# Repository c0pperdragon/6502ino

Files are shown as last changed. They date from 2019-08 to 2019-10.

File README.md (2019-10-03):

# 6502ino

A minimal circuit to form the environment necessary to run a 65c02 CPU.

Normally getting any form of 6502 processor to run and communicate with the outside
world is very cumbersome. In addition to the CPU and RAM you need very specific 
IO controller parts that can be hooked up to the system address and data bus.
You need a ROM for the initial boot code and some form of MMU to drive the various
selection lines according to the memory address (all IO is memory mapped).
All this leads to a pretty large and costly board even for the most basic 
program to execute.

This project tries to reduce the system size as much as possible by
using a microcontroller - in the form of an Arduino Uno - to do all the
tricky stuff. Together with only a bit of 7400 series logic and 32KB RAM,
this is  enough to get the 65c02 working with 16Mhz on a breadboard.

### Setting the fuses to generate 16Mhz on pin 8

For the setup to work, you need to configure your arduino to permanently
ouput the full system clock on a dedicated pin. This feature can not be set up
from inside a program, but needs to be done by configuring the "fuse bits". 

Setting the fuse bits is a bit complicated, but you only need to do it once. 
To access these bits, you need a dedicated programming device, called the 
AVR ISP (in-circuit-programmer). Luckily any arduino can be programmed to become 
such a device with the "ArduinoISP" example sketch that is included in the 
Arduino IDE. So you basically need a spare arduino for this process.

Wiring up the programmer arduino to the arduino being programmed can be seen in
countless internet resources. But there it is mainly done to programm a bootloader.
You need to do a different thing, for which you need the command-line tool "avrdude.exe"
which is installed along with the Arduino IDE somewhere in the depth of the "hardware/tools"
folder. 

Once everything is hooked up, open a system console and execute the following command (replace com10 
with whatever port your programmer arduino is registered in the system):
```
avrdude -p atmega328p -b 19200 -C ../etc/avrdude.conf -c avrisp -P com10
```

If everything works correctly, this will show you some status and the current settings of the
fuse bits. We are particularly interested in the value of the 'L' fuse bits, which on my
factory default Arduino Uno shows as L:FF. To set the permanent clock output, you need
to modify this value (an 8-bit value) to have the bit 6 set to 0. In my case this means

to set the 'L' fuses to BF:
```
avrdude -p atmega328p -b 19200 -C ../etc/avrdude.conf -c avrisp -P com10 -U lfuse:w:0xBF:m
```

After this settings are done, the Arduino will constantly send a 16Mhz signal on pin 8, 
no matter what, even during reset.

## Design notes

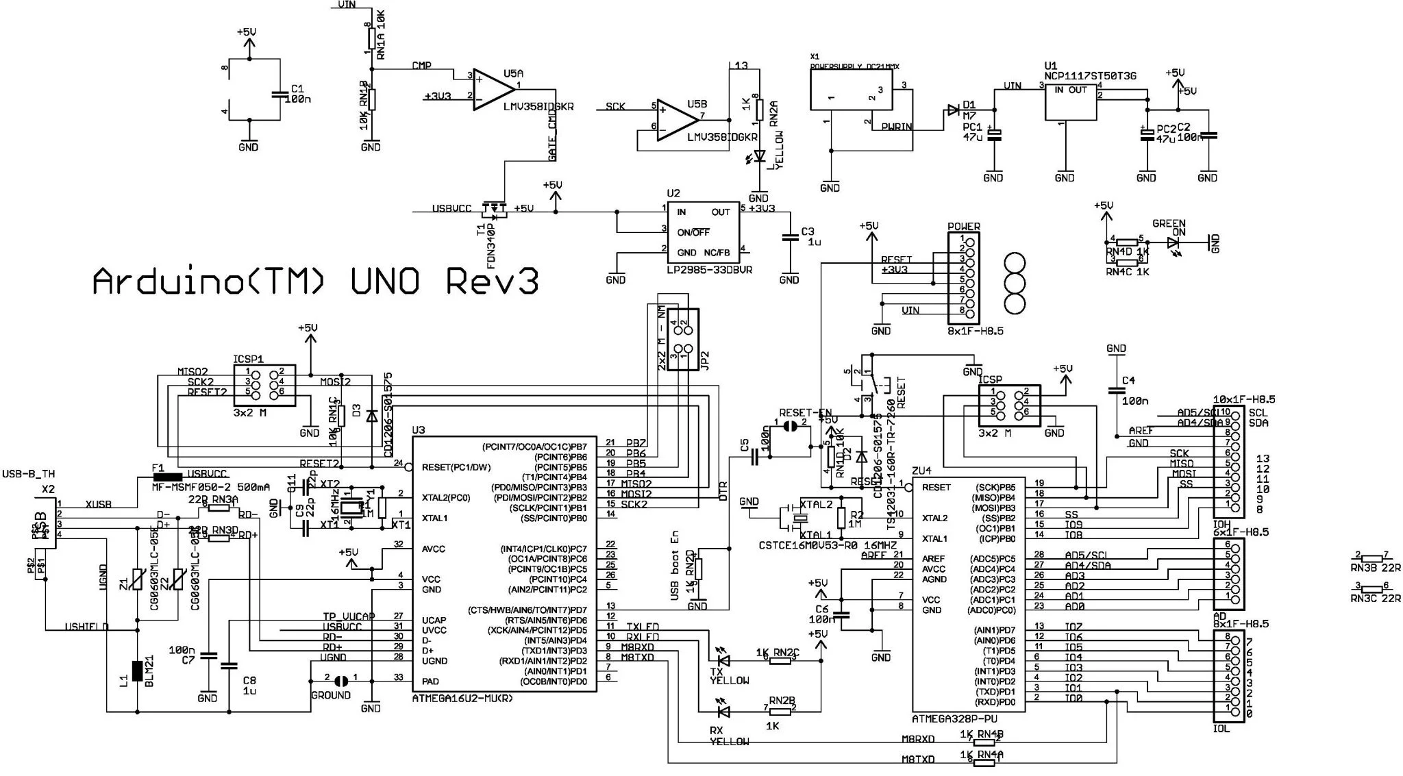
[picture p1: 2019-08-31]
doc/Arduino-Uno-R3-Schematic-Diagram.webp

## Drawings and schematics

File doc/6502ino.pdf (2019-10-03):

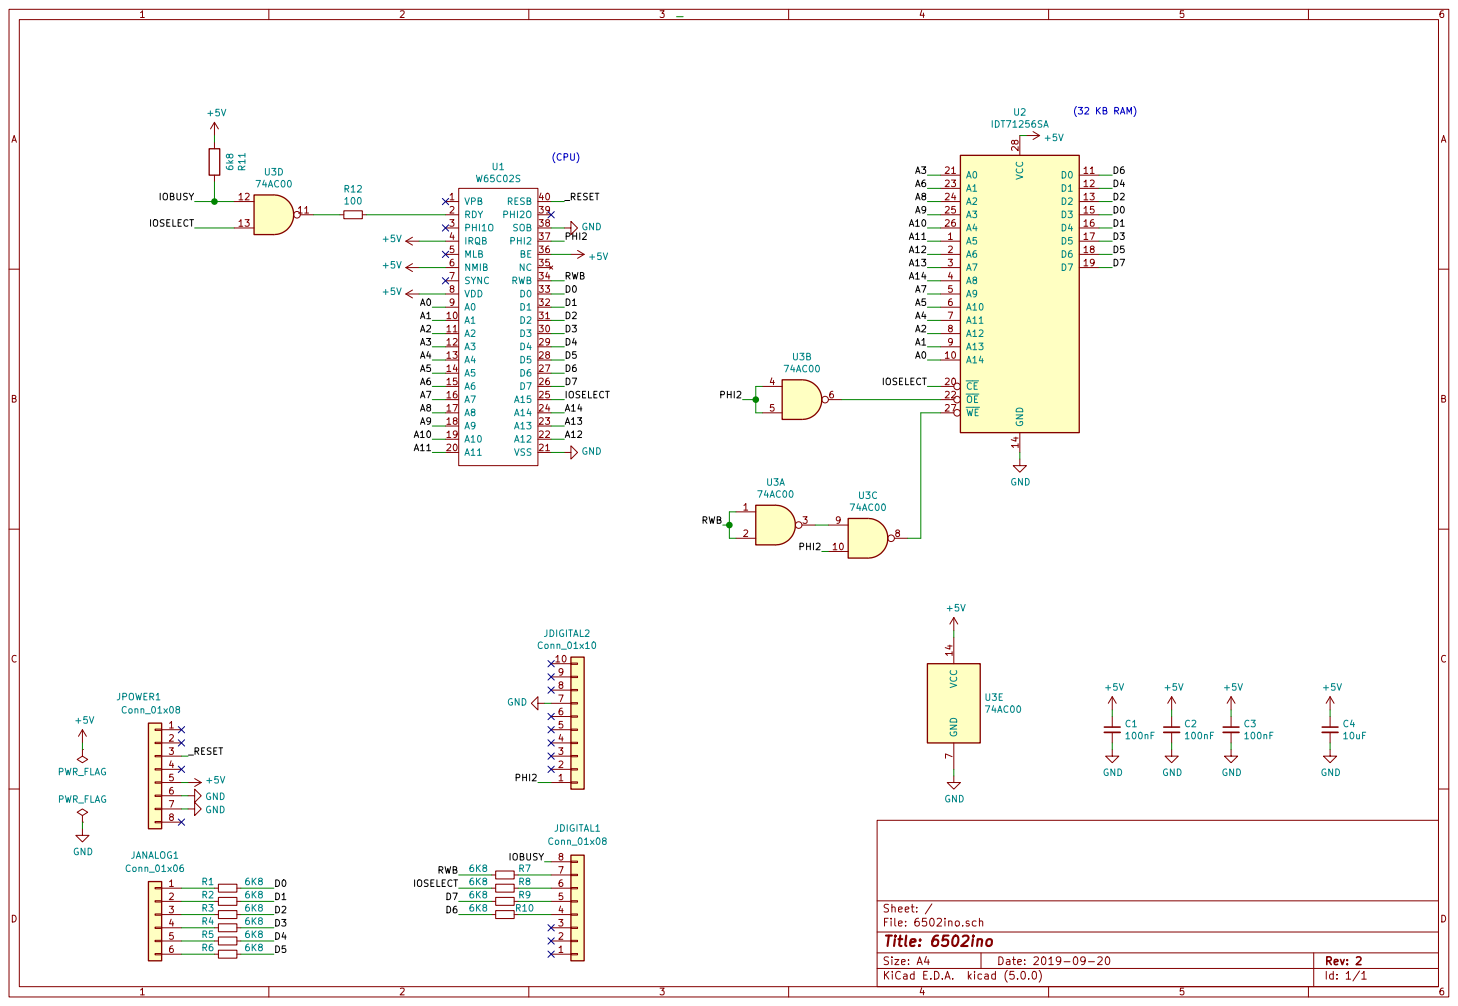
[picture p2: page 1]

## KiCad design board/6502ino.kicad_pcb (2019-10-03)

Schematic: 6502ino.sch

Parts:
C1, C2, C3: 100nF; C_Disc_D3.0mm_W1.6mm_P2.50mm
C4: 10uF; C_Disc_D4.3mm_W1.9mm_P5.00mm
JANALOG1: Conn_01x06; PinSocket_1x06_P2.54mm_Vertical
JDIGITAL1: Conn_01x08; PinSocket_1x08_P2.54mm_Vertical
JDIGITAL2: Conn_01x10; PinSocket_1x10_P2.54mm_Vertical
JPOWER1: Conn_01x08; PinSocket_1x08_P2.54mm_Vertical
R1, R2, R3, R4, R5, R6, R7, R8, R9, R10: 6K8; R_Axial_DIN0207_L6.3mm_D2.5mm_P7.62mm_Horizontal
R11: 6k8; R_Axial_DIN0207_L6.3mm_D2.5mm_P7.62mm_Horizontal
R12: 100; R_Axial_DIN0207_L6.3mm_D2.5mm_P7.62mm_Horizontal
U1: W65C02S; DIP-40_W15.24mm_Socket
U2: IDT71256SA; DIP-28_W7.62mm_Socket
U3: 74AC00; DIP-14_W7.62mm_Socket

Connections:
+5V: C1.1, C2.1, C3.1, C4.1, JPOWER1.5, R11.1, U1.4, U1.6, U1.8, U1.36, U2.28, U3.14 (VCC)
/A0: U1.9, U2.10
/A1: U1.10, U2.9
/A2: U1.11, U2.8
/A3: U1.12, U2.21
/A4: U1.13, U2.7
/A5: U1.14, U2.6
/A6: U1.15, U2.23
/A7: U1.16, U2.5
/A8: U1.17, U2.24
/A9: U1.18, U2.25
/A10: U1.19, U2.26
/A11: U1.20, U2.1
/A12: U1.22, U2.2
/A13: U1.23, U2.3
/A14: U1.24, U2.4
/D0: R1.1, U1.33, U2.15
/D1: R2.1, U1.32, U2.16
/D2: R3.1, U1.31, U2.13
/D3: R4.1, U1.30, U2.17
/D4: R5.1, U1.29, U2.12
/D5: R6.1, U1.28, U2.18
/D6: R10.1, U1.27, U2.11
/D7: R9.1, U1.26, U2.19
/IOBUSY: JDIGITAL1.8, R11.2, U3.12
/IOSELECT: R8.1, U1.25, U2.20, U3.13
/PHI2: JDIGITAL2.1, U1.37, U3.4, U3.5, U3.10
/RWB: R7.1, U1.34, U3.1, U3.2
/_RESET: JPOWER1.3, U1.40
GND: C1.2, C2.2, C3.2, C4.2, JDIGITAL2.7, JPOWER1.6, JPOWER1.7, U1.21, U1.38, U2.14, U3.7 (GND)
unnamed: JANALOG1.1, R1.2
unnamed: JANALOG1.2, R2.2
unnamed: JANALOG1.3, R3.2
unnamed: JANALOG1.4, R4.2
unnamed: JANALOG1.5, R5.2
unnamed: JANALOG1.6, R6.2
unnamed: JDIGITAL1.4, R10.2
unnamed: JDIGITAL1.5, R9.2
unnamed: JDIGITAL1.6, R8.2
unnamed: JDIGITAL1.7, R7.2
unnamed: R12.1, U1.2
unnamed: R12.2, U3.11
unnamed: U2.22, U3.6
unnamed: U2.27, U3.8
unnamed: U3.3, U3.9

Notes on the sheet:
(32 KB RAM)
(CPU)

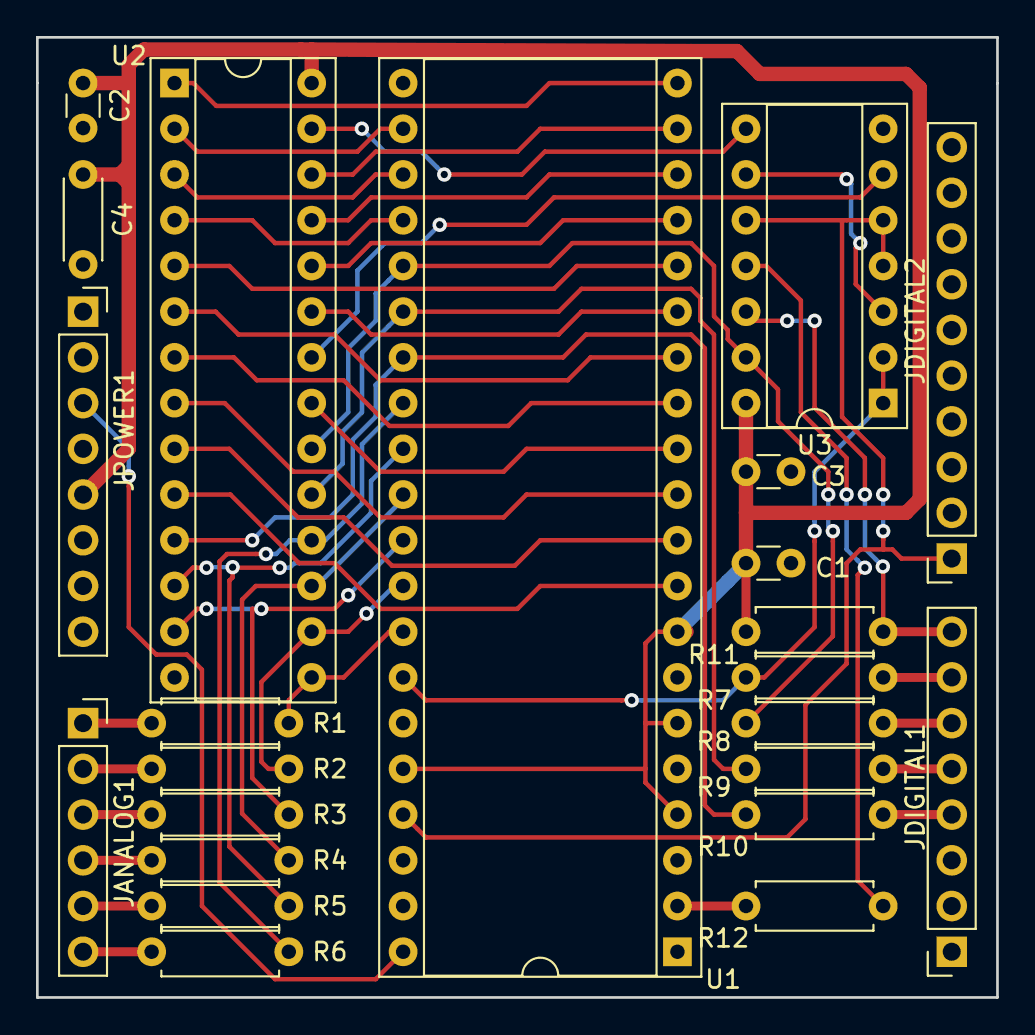
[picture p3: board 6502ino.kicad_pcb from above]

Board: 2 copper layers, 53.3 x 53.3 mm, 23 parts (0 on the bottom side), 45 nets.

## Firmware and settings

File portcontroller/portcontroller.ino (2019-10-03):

void setup()
{
  Serial.begin(9600);

  // configure signal input pins
  pinMode(5, INPUT); // IO request (active=0)
  pinMode(6, INPUT); // RWB (read=1)

  // configure bidirectional data pins to default non-pullup tri-state
  pinMode(A0, INPUT);  // D0
  pinMode(A1, INPUT);  // D1
  pinMode(A2, INPUT);  // D2
  pinMode(A3, INPUT);  // D3
  pinMode(A4, INPUT);  // D4
  pinMode(A5, INPUT);  // D5
  pinMode(3, INPUT);   // D6
  pinMode(4, INPUT);   // D7

  // configure signal output pints
  digitalWrite(7, HIGH);
  pinMode(7, OUTPUT);  // IO ACK
}

void loop()
{
  byte data;

  int tries;
  for (tries = 0; tries < 100000; tries++)
  {
    // wait until the 65c02 requests IO
    while ((PIND & 0x20) == 0)  { };

    // read access
    if (PIND & 0x40)
    {
      // perform io operation
      data = readIO();

      // distribute the byte to port C and port D (keep ack inactive yet)
      PORTC = data & 0x3F;
      PORTD = ((data >> 3) & 0x18) | 0x80;
      DDRC = 0x3F;
      DDRD = 0x98;

      // add small delay to let outgoing signals get through the resistors
      DDRD = 0x98;
      DDRD = 0x98;
      DDRD = 0x98;
      DDRD = 0x98;
      DDRD = 0x98;
      DDRD = 0x98;
      DDRD = 0x98;
      DDRD = 0x98;
      DDRD = 0x98;

      noInterrupts();

      // pulse the ACK for exactly one clock
      PORTD = ((data >> 3) & 0x18);
      PORTD = 0x98;

      // bring bidirectional ports back to idle state
      DDRC = 0x00;
      DDRD = 0x80;
      PORTC = 0x00;

      interrupts();
    }
    // write access
    else
    {
      // small delay to let inputs stablize
      PORTD = 0x80;
      PORTD = 0x80;
      PORTD = 0x80;
      PORTD = 0x80;

      // collect data from port C and D
      data = (PINC & 0x3F) | ((PIND & 0x18) << 3);

      // perform io operation
      writeIO(data);

      // pulse the ACK for exactly one clock
      noInterrupts();

      PORTD = 0x00;
      PORTD = 0x80;

      interrupts();
    }
  }

  // stop program
  for (;;);
}


byte romcounter = 0;
const PROGMEM byte rom[] =
{
  // First data the 65c02 reads from IO space are NOP instructions.
  // When interpreted as the reset vector, the program counter will
  // be set to EAEA, and quite some additional NOPs are executed
  0xEA, 0xEA, 0xEA, 0xEA, 0xEA, 0xEA, 0xEA, 0xEA,
  0xEA, 0xEA, 0xEA, 0xEA, 0xEA, 0xEA, 0xEA, 0xEA,
  // because I do not know which byte the 65c02 takes for the
  // opcode, and which byte is just an idle fetch, I insert
  // a specific command that is crafted to bring the 65c02
  // onto the right track.
  // this is either LDA zp,x  (3 data fetches)
  // or a           LDA zp    (2 data fetches)
  0xB5, 0XA5, 0x00,
  // build this copy loop at address $0000:
  //      0000 AD FF FF   LDA $FFFF
  //      0003 8D 00 20   STA $0200
  //      0006 E6 04      INC $04
  //      0008 D0 F6      BNE -10
  //      000A E6 05      INC $05
  //      000C 10 F2      BPL -14
  //      000E 4C 00 70   JMP $7000
  0xA9, 0xAD, 0x85, 0x00,   // LDA imm, STA zp
  0xA9, 0xFF, 0x85, 0x01,   // LDA imm, STA zp
  0xA9, 0xFF, 0x85, 0x02,   // LDA imm, STA zp
  0xA9, 0x8D, 0x85, 0x03,   // LDA imm, STA zp
  0xA9, 0x00, 0x85, 0x04,   // LDA imm, STA zp
  0xA9, 0x02, 0x85, 0x05,   // LDA imm, STA zp
  0xA9, 0xE6, 0x85, 0x06,   // LDA imm, STA zp
  0xA9, 0x04, 0x85, 0x07,   // LDA imm, STA zp
  0xA9, 0xD0, 0x85, 0x08,   // LDA imm, STA zp
  0xA9, 0xF6, 0x85, 0x09,   // LDA imm, STA zp
  0xA9, 0xE6, 0x85, 0x0A,   // LDA imm, STA zp
  0xA9, 0x05, 0x85, 0x0B,   // LDA imm, STA zp
  0xA9, 0x10, 0x85, 0x0C,   // LDA imm, STA zp
  0xA9, 0xF2, 0x85, 0x0D,   // LDA imm, STA zp
  0xA9, 0x4C, 0x85, 0x0E,   // LDA imm, STA zp
  0xA9, 0x00, 0x85, 0x0F,   // LDA imm, STA zp
  0xA9, 0x02, 0x85, 0x10,   // LDA imm, STA zp
  // start the copy loop
  0x4C, 0x00, 0x00,         // JMP $0000

  // this is the actual program that will go to $0200
  0xA2, 0x00,                             // 0200  LDX #0
  0xA0, 0x0D,                             // 0202  LDY #13
  0xBD, 0x10, 0x02,                       // 0204  LDA $0210,X
  0x8D, 0xFF, 0xFF,                       // 0207  STA $FFFF
  0xE8,                                   // 020A  INX
  0x88,                                   // 020B  DEY
  0xD0, 0xF6,                             // 020C  BNE -10
  0xF0, 0xFE,                             // 020E  BEQ -2
  72, 69, 76, 76, 79, 32, 87, 79, 82, 76, 68, 33, 10, // 0210  "HELLO WORLD!\n"

  // fill rest of memory with NOPs
  0xEA
};



byte readIO()
{
  byte value;

  //    delay(1);

  value = pgm_read_byte(&rom[romcounter]);

  if (romcounter < sizeof(rom) - 1)
  { romcounter++;
  }
  //    Serial.print("READ ");
  //    Serial.print(value,HEX);
  //    Serial.println();

  return value;
}

void writeIO( byte value)
{
  //    Serial.print("WRITE ");
  //    Serial.print(value, HEX);
  //    Serial.println();
  Serial.write(value);
}

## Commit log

2019-08-31 First schematics and PCB
    [6502ino.kicad_pcb, 6502ino.sch]
2019-09-14 Reduce number of ICs to 3, first working arduino sketch
    [6502ino.kicad_pcb, 6502ino.sch]
2019-09-18 Fiddling with the layout
    [6502ino.kicad_pcb, 6502ino.sch]
2019-09-20 PCB layout Rev. 1
    [6502ino-B.Cu.gbr, 6502ino-B.Mask.gbr, 6502ino-B.SilkS.gbr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]
2019-10-03 Fix: Connect BE to +5V
    [6502ino.kicad_pcb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]
